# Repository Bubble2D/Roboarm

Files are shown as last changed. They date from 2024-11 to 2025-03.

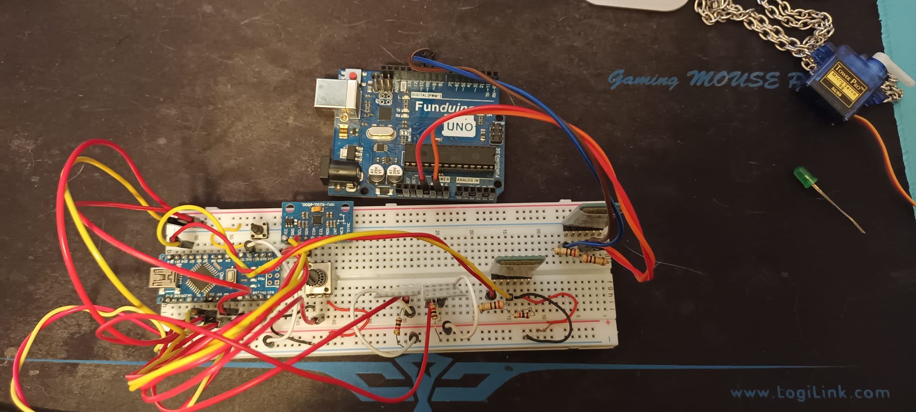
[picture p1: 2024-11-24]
Schaltkreisbild-Input-Stand-2024-11-23.jpg

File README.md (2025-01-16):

<p align="center"> 
  
  <br> Jugend forscht Projekt von V. B. 2024/25</p>

## About My Projekt

<p align="center"> Titel:<p> Entwicklung eines ferngesteuerten Arms </p> </p>

<p align="center"> Kurzbeschreibung: <p> Mein Ziel ist es einen ferngesteuerten Arm zu entwickeln, mit welchem man beispielsweise gefährliche Experimente risikofrei durchführen kann. 
                  Hierzu sammeln Sensoren an einer Hand die Daten und übermittel sie via Bluetooth an einen Arduino, welcher den 3D gedruckten Arm steuert. </p> </p>

<p align="center"> Das hier ist das offizielle Repository, für mein Jugend forscht Projekt</p>

## Quellenverzeichnis

<ol>
  <ul>
      <li><a href="https://wolles-elektronikkiste.de/hc-05-und-hc-06-bluetooth-module"> Ansteuern von Bluetooth-Modulen </a>
      <br> genutzte Programme in "https://github.com/Bubble2D/Roboarm/bluetooth_WHO_AM_I" zum Konfigurieren</li>
      <li><a href="https://wolles-elektronikkiste.de/mpu9250-9-achsen-sensormodul-teil-1"> Ansteuern von MPU9250 </a>
      <br> genutzt in "https://github.com/Bubble2D/Roboarm/Input", Nutzung von empfohlener Libary </li>
      <li><a href="https://wolles-elektronikkiste.de/serial-und-softwareserial"> Wie funktioniert Software Serial und TX|RX Protocol (I2C) </a></li>
      <li><a href="https://docs.arduino.cc/hardware/nano/">Datenblätter für Arduino Nano</a></li>
      <li><a href="https://www.youtube.com/playlist?list=PL_28gc6LBA1ve8Aamf1izQjNlqgtBWoLS">Tutorials für 3D-Moddelierung</a></li>
      <li><a href="https://domoticx.net/wp-content/uploads/catalog/elektro/motoren/servo-mini-towerpro-sg90-9g-details.jpg">Datenblatt Servo</a></li>
      <li><p> Inspiration 3D-Modell Hand</p> 
	<ul>
		<li><a href="https://external-content.duckduckgo.com/iu/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">Inspiration für Gelenk</a></li></li> 
		<li><a href="https://www.mdpi.com/1424-8220/20/15/4174#">Erklärung von "four bar linkage" Mechanismus an Fingermodulen</a></li> 
	</ul>
      </li>
  </ul>
  
</ol>

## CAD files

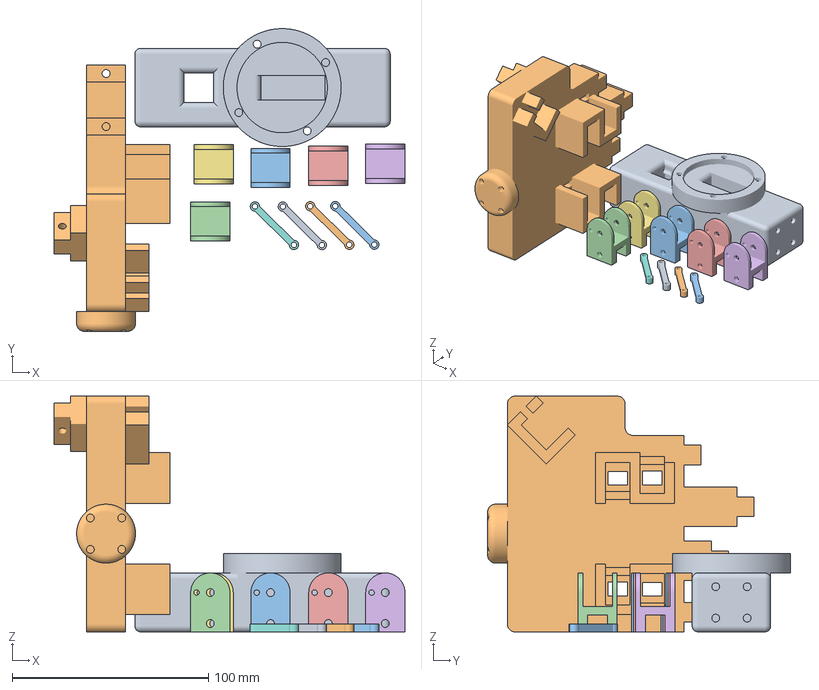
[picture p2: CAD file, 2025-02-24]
3D-Models/3mf-Files/ausbesserung.3mf
178.7 x 154.1 x 120.0 mm
Handgelenk
Handfläche
Finger-FingerFingerbasis x 5
Finger-FingerConnector-Binder_kleinTyp2 x 4

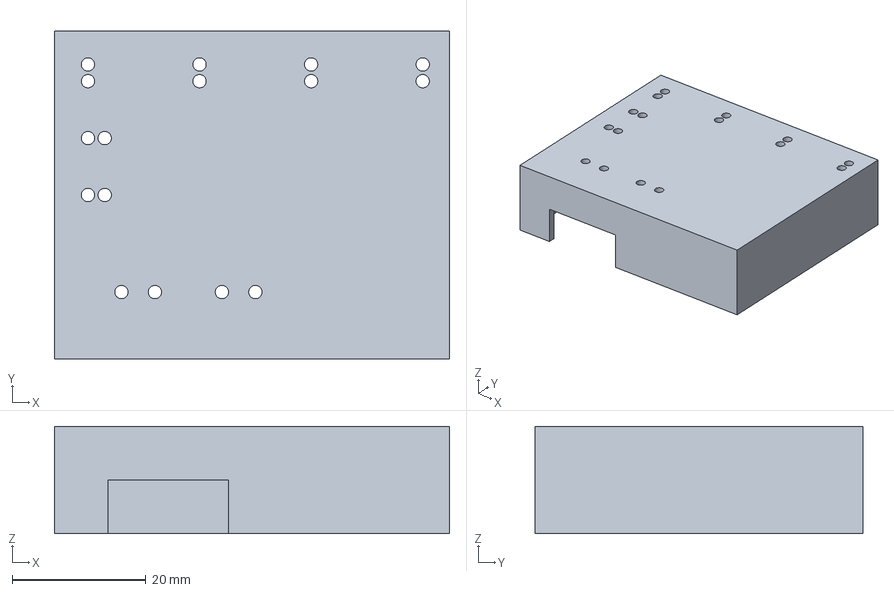
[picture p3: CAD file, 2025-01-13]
3D-Models/3mf-Files/Handschuh/Models-HalterungenDeckel.3mf
59.0 x 49.0 x 16.0 mm

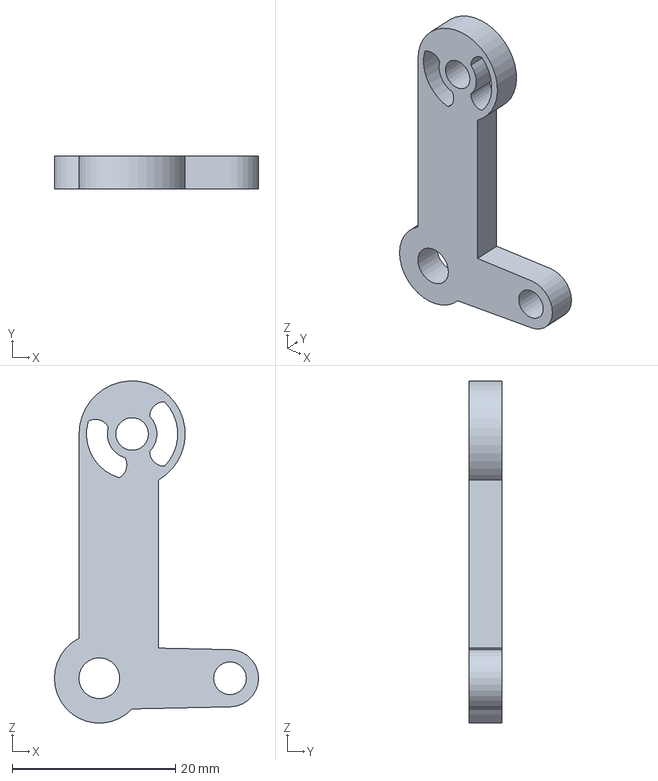
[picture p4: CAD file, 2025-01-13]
3D-Models/3mf-Files/Handteile/Fingerteile/Connector Typ 1/Finger-FingerConnector_groß.3mf
25.0 x 4.00 x 41.9 mm

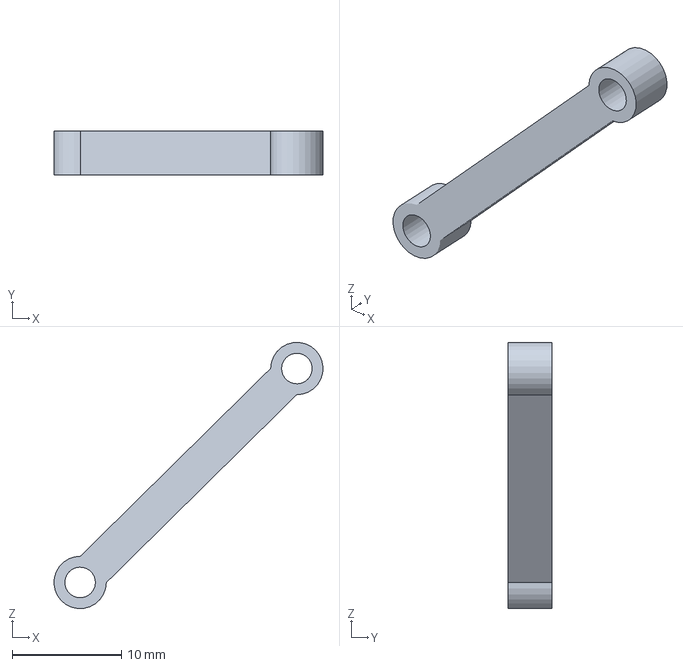
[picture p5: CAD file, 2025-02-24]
3D-Models/3mf-Files/Handteile/Fingerteile/Connector Typ 2/Finger-FingerConnector-Binder_kleinTyp2.3mf
24.6 x 4.00 x 24.4 mm

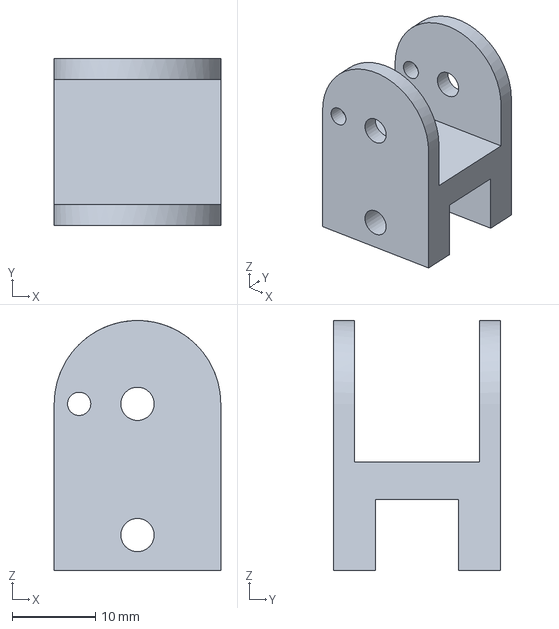
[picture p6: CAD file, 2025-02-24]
3D-Models/3mf-Files/Handteile/Fingerteile/Finger-FingerFingerbasis.3mf
20.0 x 20.0 x 30.0 mm

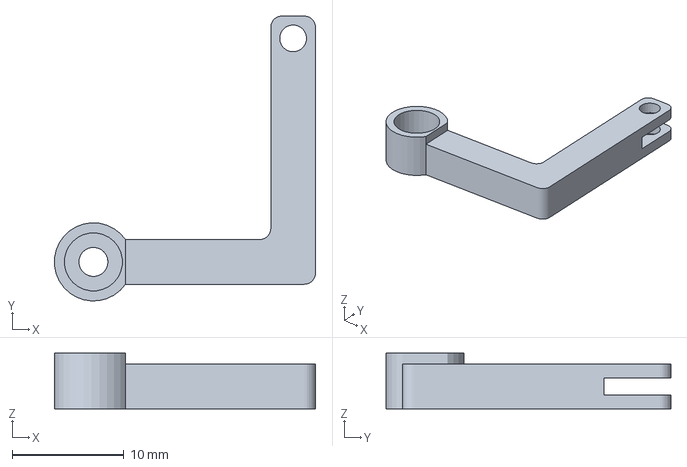
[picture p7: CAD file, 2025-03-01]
3D-Models/3mf-Files/Handteile/Fingerteile/ServoPins/ServoAufsatz-Körper-Servo-Spiegel.3mf
23.4 x 25.5 x 5.00 mm

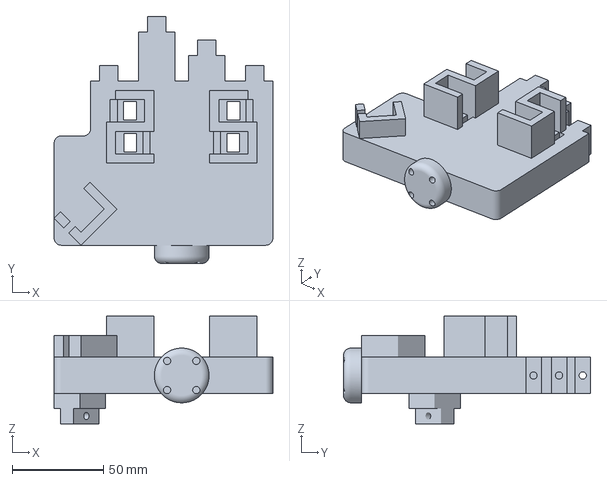
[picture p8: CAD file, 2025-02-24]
3D-Models/3mf-Files/Handteile/Handfläche.3mf
120.0 x 135.5 x 59.0 mm

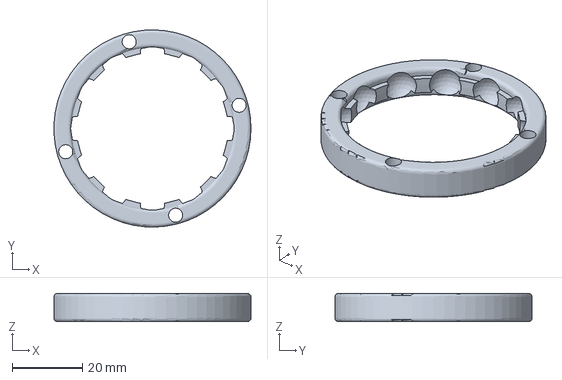
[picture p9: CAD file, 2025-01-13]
3D-Models/3mf-Files/Handteile/KugelLager/KugelLager2-Außenlager.3mf
56.0 x 56.0 x 8.00 mm

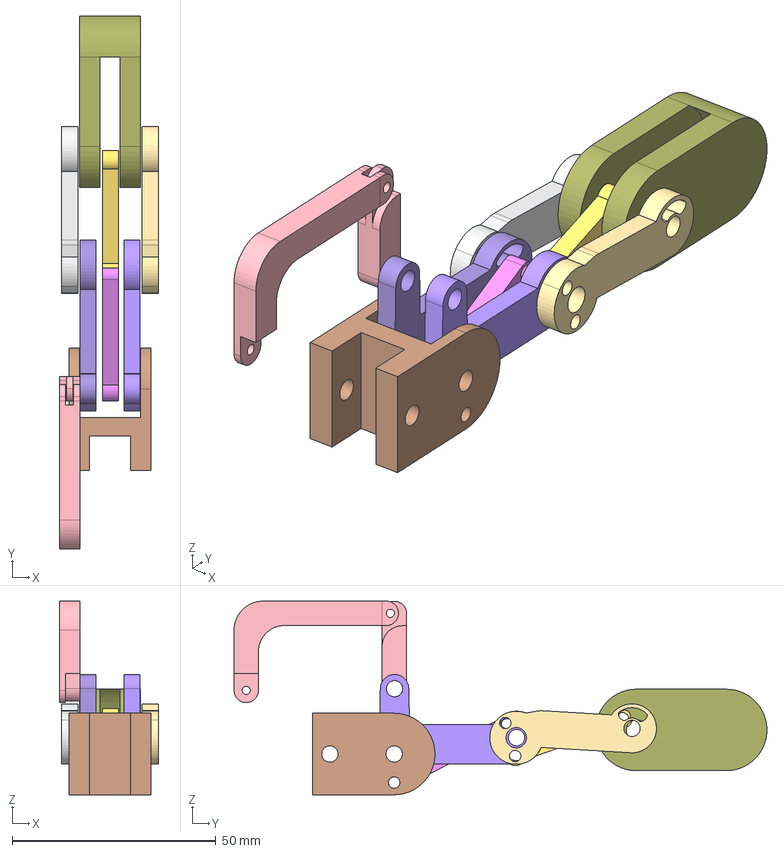
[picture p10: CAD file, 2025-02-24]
3D-Models/Hand/Finger.FCStd
24.3 x 130.7 x 47.5 mm
Fingerbasis
Connector_groß
Connector-Klon
Connector-Binder
Connector_klein
Connector-Klon2
Connector-Binder_klein
Fingerkuppe
ServoPin_Servo
ServoPin_Finger

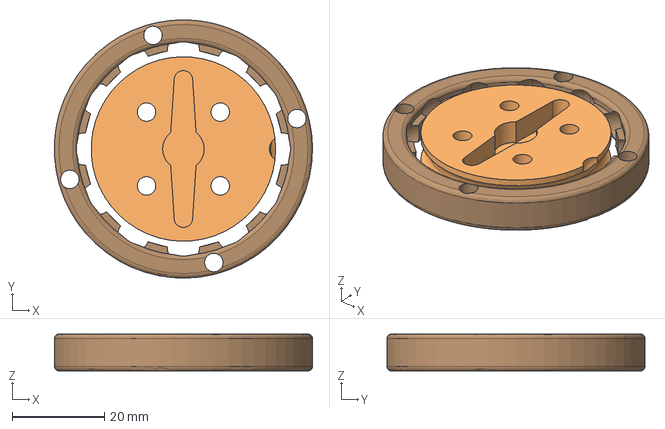
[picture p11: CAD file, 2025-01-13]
3D-Models/Hand/Servo/Kugellager/KugelLager2.FCStd
56.0 x 56.0 x 8.00 mm
Innenlager
Außenlager

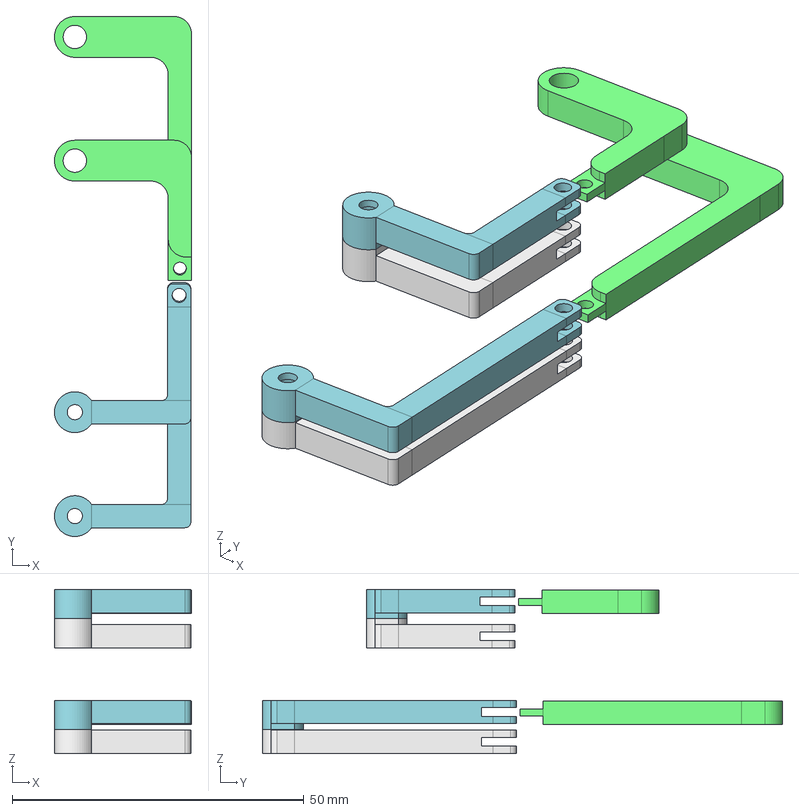
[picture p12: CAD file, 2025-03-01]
3D-Models/Hand/Servo/ServoAufsatz.FCStd
23.5 x 89.1 x 28.1 mm
ZeigeServo
Zeigefinger
MittelServo
Mittelfinger
ZeigeServo (Mirror #1)
MittelServo (Mirror #2)

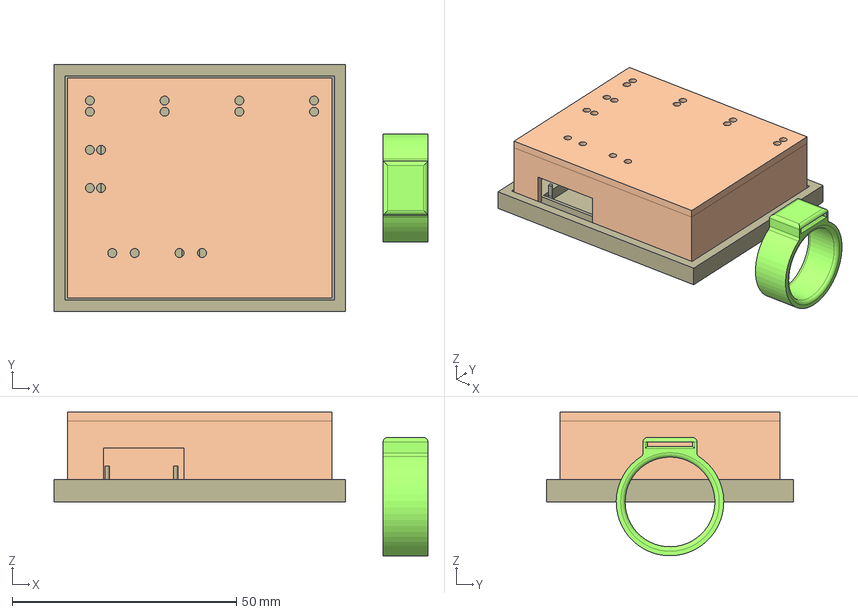
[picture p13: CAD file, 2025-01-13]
3D-Models/Handschuh/Models.FCStd
83.4 x 55.0 x 32.0 mm
Ring
Boden
Deckel

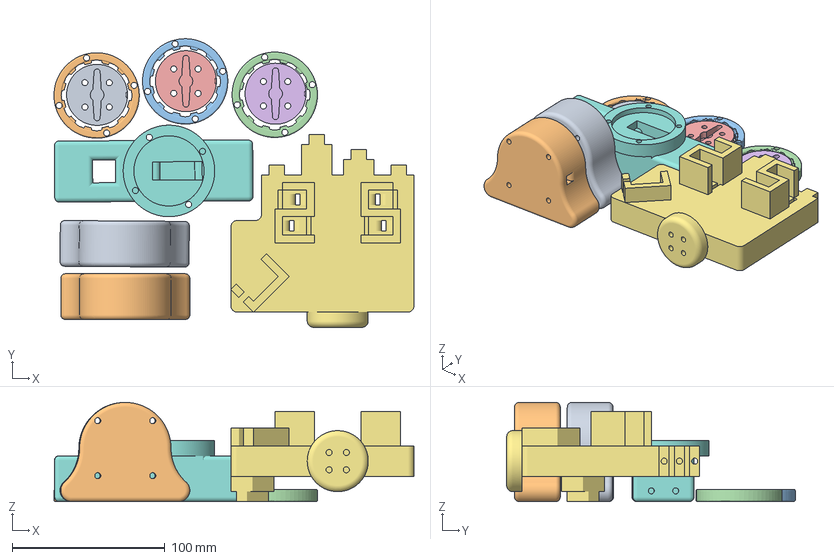
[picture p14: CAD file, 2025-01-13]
3D-Models/3mf-Files/Alle Hand Teile.3mf
236.0 x 189.2 x 65.0 mm
KugelLager2-Innenlager x 3
KugelLager2-Außenlager x 3
Handfläche
Handgelenk
Gelenkthalterung x 2

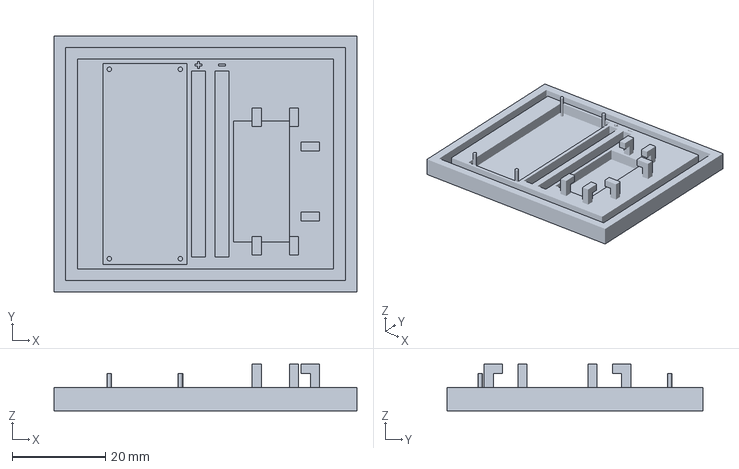
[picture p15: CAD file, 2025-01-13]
3D-Models/3mf-Files/Handschuh/Models-HalterungenBoden.3mf
65.0 x 55.0 x 10.0 mm

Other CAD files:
3D-Models/3mf-Files/Handteile/Fingerteile/Connector Typ 1/Finger-FingerConnector-Binder_groß.3mf
3D-Models/3mf-Files/Handteile/Fingerteile/Connector Typ 2/Finger-FingerConnector-Binder_klein.3mf
3D-Models/3mf-Files/Handteile/Fingerteile/Finger-komplett.3mf
3D-Models/3mf-Files/Handteile/Fingerteile/ServoPins/ServoAufsatz-Körper-Servo-lang.3mf
3D-Models/3mf-Files/Finger und Handgelenk.3mf
3D-Models/3mf-Files/Handteile/Fingerteile/Connector Typ 2/Finger-FingerConnector_klein.3mf
3D-Models/3mf-Files/Handteile/Fingerteile/Finger-DaumenDaumenkuppe.3mf
3D-Models/3mf-Files/Handteile/Fingerteile/Finger-FingerFingerkuppe.3mf
3D-Models/3mf-Files/Handteile/Fingerteile/ServoPins/Finger-FingerServoPin.3mf
3D-Models/3mf-Files/Handteile/Fingerteile/ServoPins/Finger-FingerServoPin_Finger.3mf
3D-Models/3mf-Files/Handteile/Fingerteile/ServoPins/Finger-FingerServoPin_Servo.3mf
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

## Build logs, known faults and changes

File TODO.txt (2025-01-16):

/*        TO DO - Input
//////////////////////////////
          Object für Flex-Sensor erstellen 	✔
                    Werte "übersetzen"   	✔

          Bewegungs Sensorwerte speichern -> Libary & Docs gefunden: https://wolles-elektronikkiste.de/mpu9250-9-achsen-sensormodul-teil-1
                     Werte "übersetzen" 	✔

          Fingerspreizung messen		(aufgrund von Mechanik entfernt) Ⅹ
                     Werte "übersetzen"		✔
                     
          Werte wireless transmitten		✔
              Flex-Sensor			✔
              Bewegungs-Sensor			✔
              Fingerspreizung 			Ⅹ	

	Kalibrierung von MPU9250 & FlexSensoren überarbeiten/einführen ✔
	LED's für Kallibrierung			✔

*/

Probleme:

1) FlexObjekte abspeichern bzw aufrufen // C++ kann keine Objekte wie Java in einem Array speichern, da OOP noch nicht implementiert
2) Alter versuch der Datenübertragung 	// gescheitert: Empfangen/Einlesen dauert zu lange
  					-> lag an Einlesen HC05.readString() = sehr langsam -> nutze read() und encode/decode algorhitmus
  					String sendMsg = CreateSendMsg(); sendMsg hat Form von: <(A[0-7]-[0-180]){5}\(|)([-180-180]\(|)){2}>
					bsp: <14-2|15-2|16-2|17-2|20-2|-0.00|0.00>
3)befehl mySerial.parseInt() wäre perfekt -> auch zu langsam zurück zu read()	

/*        TO DO - Output
//////////////////////////////
	Bewegung von einzelnen Fingern		✔
		Beugung				✔
		Handöffnung			Ⅹ
	Drehung von Handmotoren			✔

*/

Probleme:
1) einzelne Kommunikation klappt, ABER -> "bitshift" Wertespeicherung verschiebt sich um 1 Slot Flex0 -> Flex 1; Flex1-> Flex2, … roll -> Flex0
					   sobald alle Werte in Schleife abgefragt werdene	
							-> gelöst aber ka warum? 
						-> hatte was mit dem Timing vom Nano zu tun; wenn dieser auch Werte ausgibt passiert "bitshift"	
2) negative Werte werden falsch angenommen -> z.b. "-1" -> "255"  ✔

/*        TO DO - 3D Modelle
//////////////////////////////
	Bewegung von einzelnen Fingern		✔
		Beugung				✔
		Handöffnung			Ⅹ
	Drehung von Handmotoren			✔

	Halterung:
		Slot für Servos			✔
	Kugellagerpins für Kugellager an entsprechende Stellen packen ✔
	
	Finger fest schrauben			✔
	Servo-Connector modellieren		✔ 1/5
	Hand abrunden				✔

	Handschuh
		Idee: Armreif um Handschuh herum um Sensoren an Handschuh zu befestigen
	
	Armreif -> Konzept gestrichen; wird angeklebt	✔
	Ringe für FlexSensoren			
	LED's für Kallibrierung			✔

*/
Probleme:
1) 	Drehung von teilen und Befestigung an gleichen Körpern -> Kugellager modelieren
2)	Ansteurern der Finger ursprunglich durch Seile geplant -> mit Drehung Gefahr von Verknotung & Unnötiger Reibung => "four bar linkage" Mechanismus

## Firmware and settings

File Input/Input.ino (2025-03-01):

#include <MPU9250_WE.h>
#include <Wire.h>
#include <SoftwareSerial.h>

const int delayTime = 50;
static const uint8_t AnalogPins[] = { A0, A1, A2, A3, A4, A5, A6, A7 };  // A4 & A5 sind SDA & SCL pins || A0-A6 belegt FlexSensoren || A7 belegt durch Potentiometer
static const uint8_t LEDPins[] = { 3, 5, 6, 9, 10 };
static const uint8_t Bluetooth_LEDPIN = 4;

static const uint8_t BUTTON_PIN = 2;
bool ButtonPressed() {
  if (digitalRead(BUTTON_PIN) == LOW) {
    delay(50);
    return true;
  }
  return false;
}

// Flex-Sensor Komponenten START
  const int AnzahlFlex = 5;

  class Flex {
  public:
    int getPORT();
    int getFlexWert();
    void setFlexWert(int NeuFlexWert);
    int FlexMessen();
    void kalibrieren();
    void kalibrieren(bool SKIP);

    Flex(int PORT, int newLED_PORT) {
      AnalogInputPORT = PORT;
      FlexWert = 0;
      LED_PORT = newLED_PORT;
      pinMode(LED_PORT, OUTPUT);
      kalibrieren();
    }

  private:
    int AnalogInputPORT;
    int16_t FlexWert;
    int LED_PORT;

    // gibt die Beugung in Winkel von 0-180 Grad wieder
    int16_t ObergrenzeAlt = 0;      // gelesene Grenzen zuerst invertiert
    int16_t UntergrenzeAlt = 1023;  // und in kallibrierung angepasst
    int16_t ObergrenzeNeu = 180;
    int16_t UntergrenzeNeu = 0;
  };

  int Flex::getPORT() {
    return AnalogInputPORT;
  }
  int Flex::getFlexWert() {
    return FlexWert;
  }
  void Flex::setFlexWert(int NeuFlexWert) {
    FlexWert = NeuFlexWert;
  }
  int Flex::FlexMessen() {
    FlexWert = analogRead(AnalogInputPORT);
    FlexWert = map(FlexWert, UntergrenzeAlt, ObergrenzeAlt, UntergrenzeNeu, ObergrenzeNeu);
    analogWrite(LED_PORT, FlexWert);
    return FlexWert;
  }
  void Flex::kalibrieren() {
    digitalWrite(LED_PORT, HIGH);
    delay(1000);
    while (!ButtonPressed()) {
      FlexWert = analogRead(AnalogInputPORT);
      analogWrite(LED_PORT, FlexWert / 4);
      if (FlexWert > ObergrenzeAlt) { ObergrenzeAlt = FlexWert; }
      if (FlexWert < UntergrenzeAlt) { UntergrenzeAlt = FlexWert; }
    }
    Serial.print("ObergrenzeAlt: ");
    Serial.print(ObergrenzeAlt);
    Serial.print("\t");
    Serial.print("UntergrenzeAlt: ");
    Serial.print(UntergrenzeAlt);
    Serial.println();
    digitalWrite(LED_PORT, LOW);
  }
  void Flex::kalibrieren(bool SKIP) {
    // durchschnitt von bereits kalibrierten Werten
    ObergrenzeAlt = 853;
    UntergrenzeAlt = 0;
  }

  Flex* FlexArray[AnzahlFlex];
  int setupFlex(int AnzahlFlex) {
    switch (AnzahlFlex) {
      case 5:
        FlexArray[4] = new Flex(AnalogPins[6], LEDPins[4]);
      case 4:
        FlexArray[3] = new Flex(AnalogPins[3], LEDPins[3]);
      case 3:
        FlexArray[2] = new Flex(AnalogPins[2], LEDPins[2]);
      case 2:
        FlexArray[1] = new Flex(AnalogPins[1], LEDPins[1]);
      case 1:
        FlexArray[0] = new Flex(AnalogPins[0], LEDPins[0]);
        break;
      default:
        return 0;
        break;
    }
    return 1;
  }

  void loopFlex() {
    for (int i = 0; i < AnzahlFlex; i++) {
      int Messwert = FlexArray[i]->FlexMessen();
      FlexArray[i]->setFlexWert(Messwert);
    }
  }
// Flex-Sensor Komponenten ENDE

// MPU9250 Komponente START
#define MPU9250_ADDR 0x68

struct Winkel {
  float pitch;  // X-Achse
  float roll;   // Y-Achse
} sendeWinkel;

MPU9250_WE MPU9250 = MPU9250_WE(MPU9250_ADDR);
int setupMPU9250() {
  Wire.begin();

  if (!MPU9250.init()) {
    Serial.println("MPU9250 does not respond");
  } else {
    Serial.println("MPU9250 is connected");
  }

  Serial.println("Position your MPU9250 flat and don't move it - calibrating");
  Serial.print(".");
  delay(330);
  Serial.print(".");
  delay(330);
  Serial.print(".");
  delay(340);

  //MPU9250.setAccOffsets(-14240.0, 18220.0, -17280.0, 15590.0, -20930.0, 12080.0);
  // oder auch folgende Methode
  MPU9250.autoOffsets();
  Serial.println("Done!");

  MPU9250.setSampleRateDivider(5);
  MPU9250.setAccRange(MPU9250_ACC_RANGE_2G);
  MPU9250.enableAccDLPF(true);
  MPU9250.setAccDLPF(MPU9250_DLPF_6);

  MPU9250.enableGyrDLPF();
  MPU9250.setGyrDLPF(MPU9250_DLPF_6);
  MPU9250.setGyrRange(MPU9250_GYRO_RANGE_1000);

  return 1;
}
void loopMPU9250() {
  sendeWinkel.pitch = MPU9250.getPitch();
  sendeWinkel.roll = MPU9250.getRoll();
}
// MPU9250 Komponente ENDE

// Bluethooth Komponente START
const uint8_t txPORT = 11;
const uint8_t rxPORT = 12;

SoftwareSerial HC05(txPORT, rxPORT);

int setupHC05() {
  HC05.begin(115200);
  String sendMsg = "Ping";
  String expectAnswer = "Pong";
  String recieveMsg = "";

  while (true) {
    digitalWrite(Bluetooth_LEDPIN, LOW);
    // Code um Verbindung zu überprüfen
    if (!(HC05.available())) {
      // keine Nachricht empfangen
      HC05.print(sendMsg);
      Serial.println(sendMsg);
      delay(500);
    } else {
      // Nachricht empfangen
      recieveMsg = HC05.readString();
      Serial.println(recieveMsg);
      digitalWrite(Bluetooth_LEDPIN, HIGH);
      if (recieveMsg.equals(expectAnswer)) {
        return 1;
      }
    }
    digitalWrite(Bluetooth_LEDPIN, HIGH);
    Serial.println("Fehler bei Bluetoothverbinung");
    Serial.println("Versuche erneut");
    delay(250);
    digitalWrite(Bluetooth_LEDPIN, LOW);
    Serial.print(".");
    delay(250);
    digitalWrite(Bluetooth_LEDPIN, HIGH);
    Serial.print(".");
    delay(250);
    digitalWrite(Bluetooth_LEDPIN, LOW);
    Serial.print(".");
    Serial.println("");
    digitalWrite(Bluetooth_LEDPIN, HIGH);
    delay(250);
    digitalWrite(Bluetooth_LEDPIN, LOW);
  }
}
static const uint8_t DataIndex[] = { 14, 15, 16, 17, 20, 88, 89 };  // siehe readData
int readData(int Index) {
  /* Plan: Empfange von Index, sende Date
                  Indexliste:
                      A0 | 14 -> Flex 1 -> pinky
                      A1 | 15 -> Flex 2 -> ring
                      A2 | 16 -> Flex 3 -> middle
                      A3 | 17 -> Flex 4 -> pointer
                      A6 | 20 -> Flex 5 -> thumb
                      X  | 88 -> pitch
                      Y  | 89 -> roll
                      sonstiges -> 0 = sende erneut
                  */
  int data;
  switch (Index) {
    case 0xe:  // 14 bzw A0
      data = FlexArray[0]->getFlexWert();
      break;
    case 0xf:  // 15 bzw A1
      data = FlexArray[1]->getFlexWert();
      break;
    case 0x10:  // 16 bzw A2
      data = FlexArray[2]->getFlexWert();
      break;
    case 0x11:  // 17 bzw A3
      data = FlexArray[3]->getFlexWert();
      break;
    case 0x14:  // 20 bzw A6
      data = FlexArray[4]->getFlexWert();
      break;
    case 88:
      data = sendeWinkel.pitch;
      break;
    case 89:
      //data = sendeWinkel.roll;
      data = map(sendeWinkel.roll, -180, 180, 0, 255);
      break;
    default:
      data = -999;
      break;
  }
  return data;
}

void loopHC05() {
  if (HC05.available()) {
    int request = (int)HC05.read();
    int data = readData(request);
    HC05.write(data);
    HC05.flush();
  }
}
// Bluethooth Komponente ENDE

  //Prüfe Sensoren & gebe Werte aus
void pruefeSensoren() {
  Serial.println("---------------------------------------------------------------------------------------------");
  Serial.print("Flex0: ");
  Serial.print(readData(DataIndex[0]));
  Serial.print("\t");

  Serial.print("Flex1: ");
  Serial.print(readData(DataIndex[1]));
  Serial.print("\t");

  Serial.print("Flex2: ");
  Serial.print(readData(DataIndex[2]));
  Serial.print("\t");

  Serial.print("Flex3: ");
  Serial.print(readData(DataIndex[3]));
  Serial.print("\t");

  Serial.print("Flex4: ");
  Serial.print(readData(DataIndex[4]));
  Serial.print("\n");

  Serial.print("pitch: ");
  Serial.print(readData(DataIndex[5]));
  Serial.print("\t");

  Serial.print("roll: ");
  Serial.print(readData(DataIndex[6]));

  Serial.println();
  Serial.println("---------------------------------------------------------------------------------------------");
}


void setup() {
  Serial.begin(9600);
  Serial.println("Los geht's");
  pinMode(BUTTON_PIN, INPUT_PULLUP);
  // FlexSensoren initialisiert
  Serial.println("Initialisiere Flex...");
  while (!setupFlex(AnzahlFlex)) {
    Serial.println("Fehler bei Flex-Initialisierung");
    Serial.println("Versuche erneut...");
  }
  Serial.println("Flex-Initialisierung erfolgreich");

  //Bewegungs/Neigungssensoren initialisiert
  while (!setupMPU9250()) {
    Serial.println("Fehler bei Bewegungssensor");
    Serial.println("Versuche erneut...");
  }
  Serial.println("Bewegungssensor erfolgreich gestartet");

  // Bluetoothmodul initialisiert
  pinMode(Bluetooth_LEDPIN, OUTPUT);
  setupHC05();
  Serial.println("Bluetoothverbinung erfolgreich hergestellt");
}

void loop() {
  // float t1 = millis();

  loopFlex();     //  loopFlex & loopMPU9250 brauchen 3-5 millisekunden zum ausführen
  loopMPU9250();  //  loopHC05 ~3 millisekunden zum ausführen
  loopHC05();     //  Schätzung: Abweichung in betrieb mit 10 millisekunden rechnen

  //pruefeSensoren();

  //  float t2 = millis();
  //  float td = t2-t1;
  //  if (td > 5) {Serial.print("td: "); Serial.println(td);}
}

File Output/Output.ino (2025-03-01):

#include <SoftwareSerial.h>
#include <Servo.h>

const int delayTime = 200;

// Bluethooth Komponente START
const uint8_t rxPORT = 10;
const uint8_t txPORT = 11;

SoftwareSerial HC05(rxPORT, txPORT);

void setupHC05() {
  HC05.begin(115200);
  String sendMsg = "Pong";
  String expectAnswer = "Ping";
  String recieveMsg = "";
  bool suche = true;

  while (suche) {
    HC05.overflow();
    if (HC05.available()) {
      recieveMsg = HC05.readString();

      if (recieveMsg.equals(expectAnswer)) {
        HC05.print(sendMsg);
        Serial.println(sendMsg);
        suche = false;
      }
    }
  }
  delay(2000);
}

static const uint8_t DataIndex[] = {14, 15, 16, 17, 20, 88, 89};
//static const uint8_t DataIndex[] = {17};

void recieveData() {
  for (int index : DataIndex) {
    HC05.write(index);
    HC05.flush();
    if (HC05.available()) {
      int data = HC05.read();
      move(index, data);
    }
    delay(delayTime/2);
  }
}

// Ansprechung von Servoobjekten
struct Hand {
  Servo pinky;
  Servo ring;
  Servo middle;
  Servo pointer;
  Servo thumb;

  struct WinkelData {
    Servo pitch;  //X-Achse
    Servo roll_1;   //Y-Achse
    Servo roll_2;   //Y-Achse
  } Drehung;
} Hand;

void move(int index, int data) {
  /* Indexliste:
              A0 | 14 -> Flex 1 -> pinky
              A1 | 15 -> Flex 2 -> ring
              A2 | 16 -> Flex 3 -> middle
              A3 | 17 -> Flex 4 -> pointer
              A6 | 20 -> Flex 5 -> thumb
              X  | 88 -> pitch
              Y  | 89 -> roll
              sonstiges -> 0 = sende erneut
          */

  switch (index) {
    case 14:
      if (data > 180) { data = 180; }
      Hand.pinky.write(data);
      break;
    case 15:
      if (data > 180) { data = 180; }
      // müssen aufgrund von aufbau gespiegelt angesteuert werden
      data = 180 - data;
      Hand.ring.write(data);
      break;
    case 16:
      if (data > 180) { data = 180; }
      // müssen aufgrund von aufbau gespiegelt angesteuert werden
      data = 180 - data;
      Hand.middle.write(data);
      break;
    case 17:
      if (data > 180) { data = 180; }
      Hand.pointer.write(data);
      break;
    case 20:
      if (data > 180) { data = 180; }
      Hand.thumb.write(data);
      break;
    case 88:
      data = map(data, 0, 255, 0, 180);
      Hand.Drehung.pitch.write(data);
      break;
    case 89:
      data = map(data, 0, 255, 0, 180);
      Hand.Drehung.roll_2.write(data);
      Hand.Drehung.roll_1.write(180-data);
      break;
    default:
      move(index, data);
  }
}

// Bluethooth Komponente ENDE

void setupHand() {
  // Servos verbinden
  Hand.pinky.attach(2);
  Hand.ring.attach(3);
  Hand.middle.attach(4);
  Hand.pointer.attach(5);
  Hand.thumb.attach(6);
  Hand.Drehung.pitch.attach(7);
  Hand.Drehung.roll_1.attach(8);
  Hand.Drehung.roll_2.attach(9);
  // Servos auf Nullposition bringen
  Hand.pinky.write(0);
  Hand.ring.write(0);
  Hand.middle.write(0);
  Hand.pointer.write(0);
  Hand.thumb.write(0);
  Hand.Drehung.pitch.write(90);
  Hand.Drehung.roll_1.write(90);   
  Hand.Drehung.roll_2.write(90);  
}

void setup() {
  // put your setup code here, to run once:
  Serial.begin(9600);
  Serial.println("Los geht's");
  setupHand();
  setupHC05();
}

void loop() {
  // float t1 = millis();
  if (!HC05.overflow()) {
    recieveData();
  }


  // float t2 = millis();
  // float td = t2 - t1;
  // Serial.print("td: ");
  // Serial.println(td);
  delay(delayTime);
}

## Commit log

2024-11-11 bluetooth konfiguration und test sketches
2024-11-12 Spreitungsgrad der Finger durch Potentiometer messen
2024-12-14 fixed Datentransfer für roll Daten, Kommunikation fertig
    [Input.ino, Output.ino]
2024-12-14 Ansatzt für Handansteuerung und auskommentierung von obsoleten Methoden
2024-12-27 3D Modelle für Roboarm modeliert (Handgelenk)
    [Assembly.FCStd, Gelenkthalterung.FCStd, Handgelenk.FCStd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]
2025-01-05 Kontrollbox für Fingersteuerung und Fingermodell
    [Assembly.FCStd, Finger.FCStd, Gelenkthalterung.FCStd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]
2025-01-08 3D Modelle verkleinert und angepasst
    [Assembly.FCStd, Finger.FCStd, Gelenkthalterung.FCStd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]
2025-01-11 Robohand zu 99.99% vervollständigt
    [Finger-FingerBinderPin.3mf, Finger-FingerConnector-Binder.3mf, Finger-FingerConnector-Binder001.3mf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]
2025-01-12 Bei 3D-Modellen nur ServoConnector anpassen
    [Finger-FingerBinderPin.3mf, Finger-FingerConnector-Binder.3mf, Finger-FingerConnector-Binder001.3mf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]
2025-01-13 kleine chnanges bei 3D Modelle & 3mfs files hinzugefügt
    [Alle Hand Teile.3mf, Finger und Handgelenk.3mf, Finger-DaumenDaumenkuppe.3mf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]
2025-01-13 Kalibrierung hinzugefügt, mit LED's, mit Fortsetzten Knopf 3D-Modelle minimal verändert
    [Finger.FCStd, Gelenkthalterung.3mf, Gelenkthalterung.FCStd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]
2025-01-13 LED's leuchten nun auch in Betriebszustand
2025-01-13 Deckel und Boden von Handschuh überarbeitet
    [Models-HalterungenBoden.3mf, Models-HalterungenDeckel.3mf, Models.FCStd]
2025-01-16 korrektur von Handfläche
    [Gelenkthalterung.3mf, Gelenkthalterung.FCStd, Handfläche.FCStd]
2025-02-24 minimale anpassungen
    [Finger-FingerConnector-Binder_kleinTyp2.3mf, Finger-FingerFingerbasis.3mf, Finger-FingerServoPin_Finger.3mf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]
2025-03-01 letztere anpassungen
    [ServoAufsatz-Körper-Finger-lang.3mf, ServoAufsatz-Körper-Servo-Spiegel.3mf, ServoAufsatz-Körper-Servo-lang-Spiegel.3mf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]
